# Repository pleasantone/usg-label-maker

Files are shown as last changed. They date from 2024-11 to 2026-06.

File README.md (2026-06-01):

# usg-label-maker

## Introduction

This is a magnetic label generator that I use to create my labels
for my Harbor Freight US General series tool boxes/tool carts.  You
can easily make a batch of custom labels for tool carts and tool
boxes.

The label generator is written to work either with the Makerworld
Parametric Model Maker (aka the Customize button) or on a local
copy of [OpenSCAD](https://openscad.org/downloads.html#snapshots).

The included .3MF project includes a ton of labels you can use on
their own, but it was my intention that you would use this to make
your own custom labels.

We print these labels with the magnet side down to the bed. The
little amount of bridging needed means that supports should not be
needed.

### Remix Differences

Originally written by Josh who produced a single label. This is
complete rewrite of that code to support batch generation, the
customizer, guardrails, and multi-part and multi-plate printing.
His code was the inspiration for this code.

## Usage

### Option 1: MakerWorld Customizer Button

#### Pros:
- Nothing to install, just customize, download, and print.
- Supports generating up to 5 plates at once.

#### Cons:

You must use one of the fonts supported by the customizer, which
does not include any that match the US General font. Montserrat is
kind of close, but not fantastic.

1. Use the customizer to set the labels you wish to print.
   Labels are delimited with the “|” character.
1. Generate, download
1. Slice and print.

### Option 2: Local OpenSCAD

#### Pros:
- Not limited to Makerworld's font library.

#### Cons:
- More complicated
- Requires OpenSCAD and font installation
- Only supports one plate at a time.
- Base and text are exported as two different parts of the object--just select which color filament to use for each part.

1. Install OpenSCAD development snapshot. The last official release is from 2021 but it is actively maintained and we use features that do not exist in the official release. Hint: if using a recent MacOS, you may need to remove the quarantine flag from the downloaded file before it will run.
1. Download/install desired fonts (see Getting the Fonts below).
1. Go to **OpenSCAD > Preferences > Features** and enable lazy-union and text-metrics.
1. Go to **OpenSCAD > Preferences > Advanced** and set the 3D Rendering backend to **Manifold**.
1. Download the `.SCAD` file, edit it and set `MakerWorld_Customizer_Environment` to `false` (it defaults to `true` for the customizer).
1. Use the OpenSCAD customizer window or edit the source code to set the labels you wish to print. *Labels are delimited with the “|” character.*
1. If using a different font, set the name of the font in OpenSCAD.
1.  Do a preview rendering (F5), if it looks good, do a slower full rendering (F6), then Export the output as a .3MF file.
1. Load the .3MF file into your slicer, answer Yes when the slicer prompts “Multi-part object detected.”
1. Go to Objects menu, “OpenSCAD Model 1” represents all the bases, “OpenSCAD Model 2” is all of the text parts. Set desired colors or filament for each part.

## Getting the fonts

You can use any TTF font you want. You can either copy the font
file into the same directory as the .scad file, or install it in
your system fonts.

The default local font is **sd prostreet**, which works well and is
freely available.

As a backup, Fontspring's [Avionic Wide Oblique
Black](https://www.fontspring.com/fonts/grype-type/avionic) is the
closest match to the actual USG font. The sample pictures were
taken with their Demo license copy so you can easily test --
obviously you should either change fonts or buy a personal license
should you use this for a finished project or commercially.

## Interesting Parameters/Variables

See the .scad file for parameters you can change, but briefly:

- *MakerWorld_Customizer_Environment*: Running on MakerWorld (true) or locally (false)?
- *plate_labels_1*..*plate_labels_5*: label names, each delimited with "|" like "SOCKETS|RATCHETS|ALLEN WRENCHES" (only plate_labels_1 is rendered locally)
- *font*: font to use; defaults follow the environment
- *font_size*: 8mm default
- *depth*: 5mm default total badge thickness -- includes raised letters
- *base_outline*:
     0: default, a rectangle with rounded corners
     1: Flows base shape to follow letter outlines.
        May produce more aesthetic results but can also look
        strange letters with descenders (angled base) and trailing Ls
        (opposite angle). Slower to render but could be very cool.

### Layout, exclusion zones, and the preview border

Labels are 2D bin-packed to fill the bed on both axes, not just stacked in a
single column. If more labels are requested than fit, rendering stops with an
assertion that names the labels it couldn't place — reduce the label count or
`font_size`, shrink the exclusion zones, or split the set across plates.

- *exclude_zone_1* / *exclude_zone_2*: optional rectangular keep-out areas the
  packer routes around, each anchored to a bed corner via its `_corner` and
  `_size` ([width, height] mm) parameters. Defaults reserve the Bambu X1C
  front-left cutter/wipe area and a prime-tower space at the top-right.
  Enabling zones reduces usable area, so a set that fit without them may
  overflow.
- *border_thickness*: width of a red reference frame drawn just outside the bed
  edges. Together with the translucent red exclusion-zone overlays it appears
  only in on-screen preview (F5) and is never part of any STL/3MF export.

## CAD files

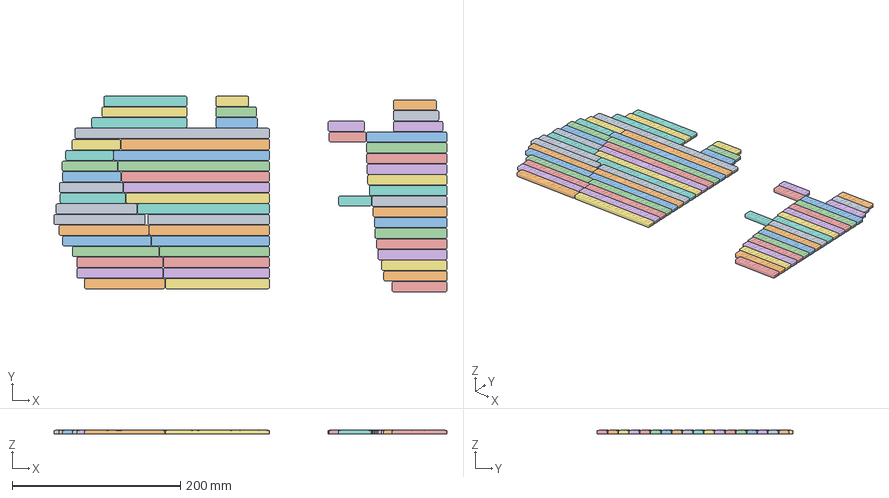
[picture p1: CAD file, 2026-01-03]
samples/New Labels (2 plates).3mf
466.9 x 232.6 x 5.00 mm
part_electrical-diagnostics.stl
part_torque-wrenches.stl
part_specialty-sockets.stl
part_automotive-tools.stl
part_impact-wrenches.stl
part_metric-wrenches.stl
part_electrical-tools.stl
part_metric-sockets.stl
part_screwdrivers.stl
part_sae-wrenches.stl
part_breaker-bars.stl
part_power-tools.stl
part_brake-tools.stl
part_sae-sockets.stl
part_motorcycle.stl
part_extensions.stl
part_measuring.stl
part_electrical.stl
part_hardware.stl
part_adhesives.stl
part_soldering.stl
part_vise-grips.stl
part_wrenches.stl
part_drill-bits.stl
part_air-tools.stl
part_pry-bars.stl
part_ratchets.stl
part_sealants.stl
part_crimpers.stl
part_hammers.stl
part_no-touch.stl
part_hex-keys.stl
part_magnets.stl
part_brushes.stl
part_marking.stl
part_sockets.stl
part_riveting.stl
part_bit-sets.stl
part_chisels.stl
part_snacks.stl
part_shears.stl
part_zip-ties.stl
part_metric.stl
part_lights.stl
part_pliers.stl
part_allen.stl
part_picks.stl
part_paint.stl
part_junk.stl
part_torx.stl
part_misc.stl
part_tape.stl
part_bits.stl
part_oils.stl
part_sae.stl
part_ppe.stl

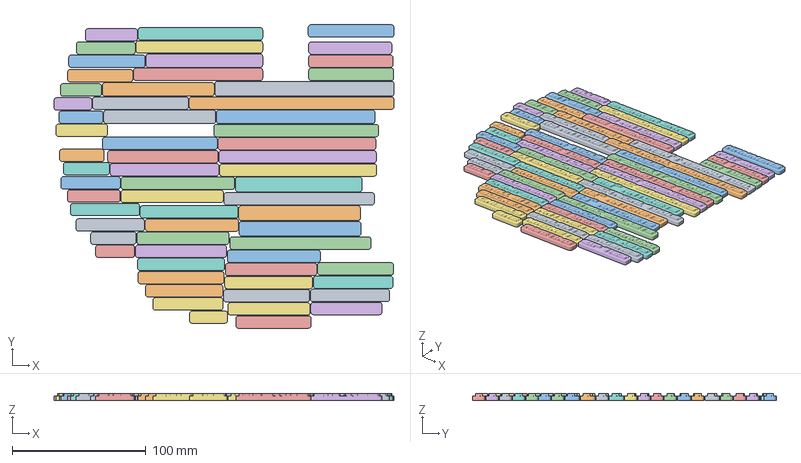
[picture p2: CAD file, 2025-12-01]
samples/sample label objects.3mf
253.9 x 226.7 x 5.50 mm
part_i-wasnt-asking-tool.stl
part_electrical-diagnostics.stl
part_torque-wrenches.stl
part_specialty-sockets.stl
part_automotive-tools.stl
part_impact-wrenches.stl
part_metric-wrenches.stl
part_38--ratchets.stl
part_electrical-tools.stl
part_12--ratchets.stl
part_14--ratchets.stl
part_metric-sockets.stl
part_sae-wrenches.stl
part_38-ratchets.stl
part_screwdrivers.stl
part_breaker-bars.stl
part_12-ratchets.stl
part_14-ratchets.stl
part_power-tools.stl
part_sae-sockets.stl
part_brake-tools.stl
part_motorcycle.stl
part_extensions.stl
part_measuring.stl
part_electrical.stl
part_hardware.stl
part_wrenches.stl
part_adhesives.stl
part_vise-grips.stl
part_soldering.stl
part_ratchets.stl
part_crimpers.stl
part_sealants.stl
part_drill-bits.stl
part_hammers.stl
part_air-tools.stl
part_no-touch.stl
part_pry-bars.stl
part_magnets.stl
part_hex-keys.stl
part_brushes.stl
part_sockets.stl
part_bit-sets.stl
part_marking.stl
part_riveting.stl
part_zip-ties.stl
part_chisels.stl
part_shears.stl
part_snacks.stl
part_metric.stl
part_pliers.stl
part_lights.stl
part_paint.stl
part_allen.stl
part_picks.stl
part_tape.stl
part_misc.stl
part_junk.stl
part_torx.stl
part_bits.stl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

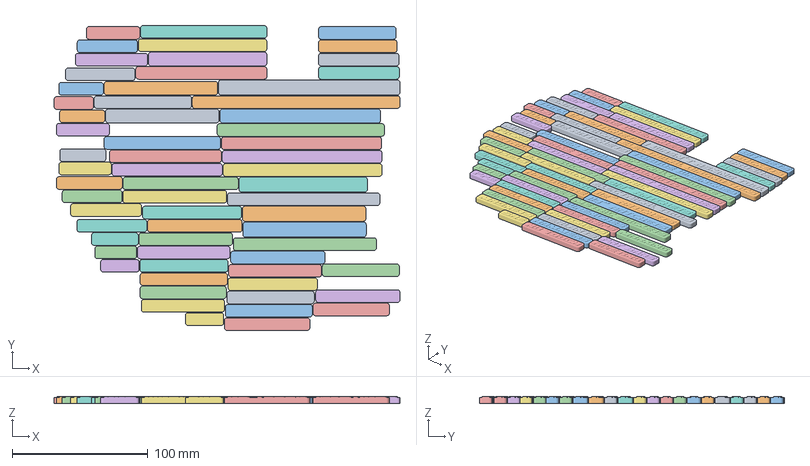
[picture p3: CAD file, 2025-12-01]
samples/MagneticLabelMaker.3mf
254.7 x 224.5 x 5.00 mm
part_i-wasnt-asking-tool.stl
part_electrical-diagnostics.stl
part_torque-wrenches.stl
part_specialty-sockets.stl
part_automotive-tools.stl
part_impact-wrenches.stl
part_metric-wrenches.stl
part_38--ratchets.stl
part_electrical-tools.stl
part_12--ratchets.stl
part_14--ratchets.stl
part_metric-sockets.stl
part_sae-wrenches.stl
part_38-ratchets.stl
part_screwdrivers.stl
part_breaker-bars.stl
part_12-ratchets.stl
part_14-ratchets.stl
part_power-tools.stl
part_sae-sockets.stl
part_brake-tools.stl
part_motorcycle.stl
part_extensions.stl
part_measuring.stl
part_electrical.stl
part_hardware.stl
part_wrenches.stl
part_adhesives.stl
part_vise-grips.stl
part_soldering.stl
part_ratchets.stl
part_crimpers.stl
part_sealants.stl
part_drill-bits.stl
part_hammers.stl
part_air-tools.stl
part_no-touch.stl
part_pry-bars.stl
part_magnets.stl
part_hex-keys.stl
part_brushes.stl
part_sockets.stl
part_bit-sets.stl
part_marking.stl
part_riveting.stl
part_zip-ties.stl
part_chisels.stl
part_shears.stl
part_snacks.stl
part_metric.stl
part_pliers.stl
part_lights.stl
part_paint.stl
part_allen.stl
part_picks.stl
part_tape.stl
part_misc.stl
part_junk.stl
part_torx.stl
part_bits.stl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

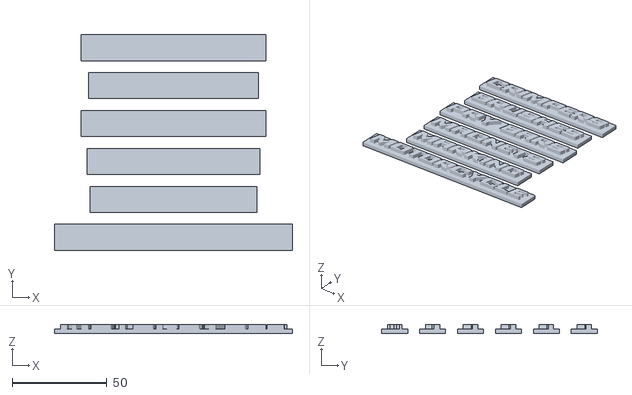
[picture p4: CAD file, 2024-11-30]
samples/labels3.stl
125.7 x 113.8 x 5.00

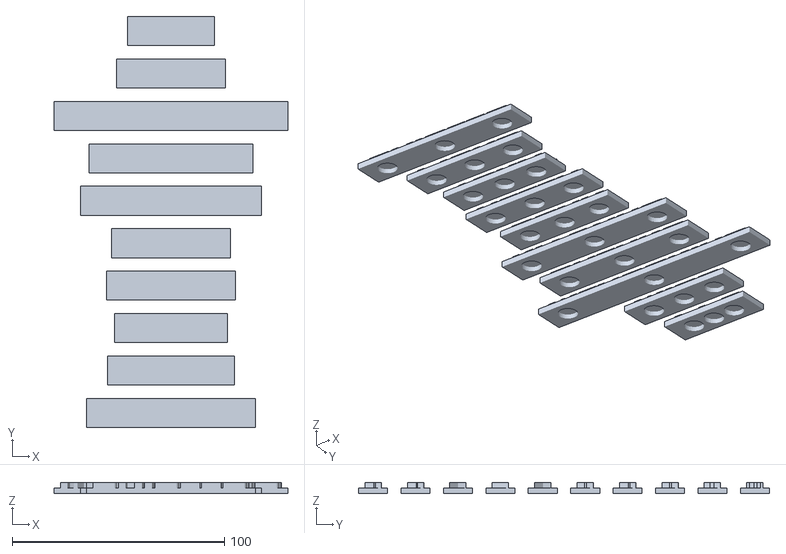
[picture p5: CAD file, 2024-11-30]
samples/labels2.stl
110.2 x 193.8 x 5.00

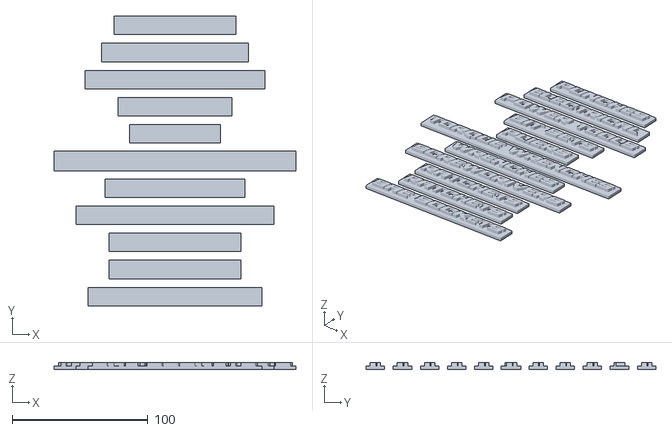
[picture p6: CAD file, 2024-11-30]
samples/labels1.stl
178.4 x 213.8 x 5.00

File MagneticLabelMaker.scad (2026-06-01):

/*
  Magnetic Label Maker by Pleasant One remixed from Josh
  See documentation for License.
  
  We have two similar but different working environments, OpenSCAD locally or
  online with a customizer like Makerworld's Parametric Model Maker
  
  With MakerWorld's product, we can support up to five plates of
  labels to be generated at once. MakerWorld's extensions allow for
  encoding color information in the .3mf.

  However, MakerWorld cannot add user fonts, so we can't get the
  closest US General matching font.  I have found that MakerWorld's
  Montserrat Extra Bold Italic is moderately close.

  With OpenSCAD locally, we only support producing one (the first)
  plate at a time.  You can generate either .STL files or .3MFs but
  no color information will be encoded.  The output file will contain
  two object parts, the base of and the text.  Load both parts
  together using your slicer, and then use your slicer to assign
  color information.
*/

// usg-label-maker release 1.0.0  (x-release-please-version -- auto-updated; do not edit by hand)

// Are we running on MakerWorld or a local instance of OpenSCAD?
MakerWorld_Customizer_Environment = true;

// The labels to print, delimited by "|"
plate_labels_1 = "METRIC SOCKETS|SAE SOCKETS|SPECIALTY SOCKETS|RATCHETS|SCREWDRIVERS|WRENCHES|TORQUE WRENCHES|PLIERS|BIT SETS|POWER TOOLS|ELECTRICAL|CHISELS|PICKS|TORX|ALLEN|JUNK|RIVETING|SHEARS|MEASURING|MISC|PPE|MOTORCYCLE|MARKING|MAGNETS|PRY BARS|BRUSHES|CRIMPERS|SOLDERING|HAMMERS|LIGHTS|ZIP TIES|TAPE|DRILL BITS|ADHESIVES|SEALANTS|AUTOMOTIVE TOOLS|OILS|PAINT|BRAKE TOOLS|HAMMERS|SAE WRENCHES|METRIC WRENCHES|VISE GRIPS|AIR TOOLS|POWER TOOLS|SNACKS|ELECTRICAL TOOLS|ELECTRICAL DIAGNOSTICS|SOCKETS|ELECTRICAL|NO TOUCH|BITS|IMPACT WRENCHES";

// Multiple plate support only works on MakerWorld
plate_labels_2 = "1/4\" RATCHETS|3/8\" RATCHETS|1/2\" RATCHETS";
plate_labels_3 = "I WASN'T ASKING TOOL";
plate_labels_4 = "DON'T TOUCH MY TOOLS";
plate_labels_5 = "PLATE 5 ITEMS";

/* [Fonts] */
/* A note on fonts:

   If you are intending to match the US General font, it is non-standard
   and is not installed on either OpenSCAD or with MakerWorld. You will need
   to download a closely matching font.
   
   The best font available on MakerWorld is Montserrat Extra Bold Italic.

   For local operation, where you can use any font you find on the web,
   the default is sd prostreet. Avionic Wide Oblique Black is the closest
   match to the actual USG font but is only available as a Fontspring demo
   download -- use it as a backup if you want the closer look. Any of these
   work well:

   https://www.ffonts.net/sdprostreet-Regular.font     (default)
   https://demofont.com/avionic-sans-serif-font/       (backup: closest USG match, demo license)
   https://www.ffonts.net/Concielian-Bold-Semi-Italic.font  (backup)

   Download one or more of them and unpack.
   Install the downloaded font(s) to your system. (On a Mac, double-click the .ttf and install.)

   You might need to restart OpenSCAD in order for it to recognize
   newly installed or "used' fonts.

   The sample pictures were taken with Avionic Wide Oblique Black's demo.
*/

// Default font follows the environment: Montserrat on MakerWorld (only fonts in
// their library are available), sd prostreet locally. Override in the customizer
// or via OpenSCAD -D for batch runs.
// Backup local options:
//   "FONTSPRING DEMO \\- Avionic Wide Oblique Black" -- closest USG match (demo license)
//   "Concielian:style=Bold Semi Italic"

// font used with makerworld customizer
makerworld_font = "Montserrat:style=ExtraBold Italic"; //font

// font used when running local OpenSCAD
local_font = "sd prostreet";

font = MakerWorld_Customizer_Environment ? makerworld_font : local_font;

// Font size in points
font_size = 8; // [5:32]

/* [Colors] */
// Base color
base_color = "#000000"; // color

// Text color
text_color = "#FFFFFF"; // color

/* [Details] */
/*
   If base_outline is true, the base will flow with letter shapes. It is slower
   to render and could be unaesthetic when using letters with descenders
   (Q) or trailing characters with reverse angles (L). It's very pretty
   when it works out correctly but, to be safe, we leave this off by default.
*/

// Should the base follow an outline of the letters? (see notes!)
base_outline = 0; // [0: Standard base, 1: Follow letter shapes]

// Rounded corner radius in mm
base_radius = 2;

// Total depth in mm of badge and base in mm
depth = 5;

// Diameter of the magnet hole in mm
magnet_diameter = 8;

// Depth of the magnet hole in mm
magnet_depth = 3;

// Fully encapsulated magnets or open at the base. If encapsulate, pause the print at the top of the hole to insert magnets
encapsulate_magnets = false;

// place magnet holes in mm from inside edge
magnet_edge_inboard = 10;

// minimum separation in mm between outer holes before dropping to one hole
magnet_minimum_separation = 2;

// if piece is >mm wide, add a center hole
magnet_center_hole_width = 60;

/* [Printer dimensions] */
// printer bed size (BambuLab A1/P1/X1 are approximately 255mmx255mm)
bed_size=[255, 255];

// Wall width in mm of the preview-only plate-edge border (never exported)
border_thickness = 3;

// Skip rectangular keep-out areas when arranging labels (each anchored to a bed
// corner). Sizes are [width, height] in mm.

// Zone 1 default: Bambu X1C front-left cutter / nozzle-wipe area (tune to taste)
exclude_zone_1 = true;
exclude_zone_1_corner = "left-bottom"; // [left-bottom, right-bottom, left-top, right-top]
exclude_zone_1_size = [18, 28];

// Zone 2 default: space reserved for a prime / purge tower
exclude_zone_2 = true;
exclude_zone_2_corner = "right-top"; // [left-bottom, right-bottom, left-top, right-top]
exclude_zone_2_size = [55, 55];

/* [Advanced] */
// Extra padding for magnet cut on Z axis
magnet_depth_clearance = 0.1;
// Extra padding for magnet at top of cut
magnet_topcyl_clearance = 0.1;
// Extra padding for magnet at bottom of cut
magnet_bottomcyl_clearance = 0.2;

// lower Z bounds of magnet cut
magnet_depth_offset = encapsulate_magnets ? magnet_depth_clearance * 2 : 0;
magnet_hole_bore = magnet_depth + magnet_depth_clearance;
magnet_hole_top = magnet_hole_bore + magnet_depth_offset;
// the .1 is slop so we can get enough material around the magnet
magnet_wrap_diameter = magnet_diameter + magnet_bottomcyl_clearance; // + 0.042;

// Safety gap in mm between neighbouring label footprints (applied on both axes)
label_gap = 1;

/* [ Hidden ] */

base_depth = magnet_hole_top + (magnet_depth_clearance*2);

// Active exclusion zones as rectangles [x_min, y_min, x_max, y_max] in the same
// bed-centered coordinate system the labels are placed in.
exclusion_zones = concat(
    exclude_zone_1 ? [corner_rect(exclude_zone_1_corner, exclude_zone_1_size, bed_size)] : [],
    exclude_zone_2 ? [corner_rect(exclude_zone_2_corner, exclude_zone_2_size, bed_size)] : []
);

$fn = 32; // Model detail, higher is more detail and more processing

/* -------------------------------------------------------------------------- */

/* Maker World Multi-plate
   The following modules will only be executed when using the
   Parametric Model Maker.
   
   We define specific modules for each plate.
   
   The name of module should be in syntax: mw_plate_1(), mw_plate_2(), etc.
*/

module mw_plate_1(labels=plate_labels_1) mw_make_labels(labels);
module mw_plate_2(labels=plate_labels_2) mw_make_labels(labels);
module mw_plate_3(labels=plate_labels_3) mw_make_labels(labels);
module mw_plate_4(labels=plate_labels_4) mw_make_labels(labels);
module mw_plate_5(labels=plate_labels_5) mw_make_labels(labels);

module mw_make_labels(labels) {
    color(base_color) iterate_labels(labels) make_base();
    color(text_color) iterate_labels(labels) make_text();
}

/* Local OpenSCAD:

   If we are using the development snapshot of OpenSCAD with the lazy_union
   enabled, each "top level" creation will be its own object part.
   This is an easy way to handle color changes.
   
   Import the .3mf file into your slicer, click "Yes" when it asks to
   bring in multiple objects as parts of one single object, and it will
   position each part correctly.
   
   Then go into the object menu and set filaments as you want them colored.
*/

if (!MakerWorld_Customizer_Environment) {
    color(base_color)
        iterate_labels(plate_labels_1)
            make_base(); // all the bases will export as a single object

    color(text_color)
         iterate_labels(plate_labels_1)
            make_text(); // all the text will export as a single object
}

// Reference frame around the bed edges plus the exclusion-zone overlays.
// $preview is true only for on-screen preview (F5); it is false during full
// render and every export (F6, CLI -o, MakerWorld), so these never become part
// of any STL/3MF.
if ($preview) {
    plate_border();
    plate_exclusions();
}


/* ------------------------ */
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

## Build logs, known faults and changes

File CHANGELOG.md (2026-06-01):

# Changelog

All notable changes to this project are documented in this file. From v1.0.0
onward it is maintained automatically by
[release-please](https://github.com/googleapis/release-please) from
[Conventional Commits](https://www.conventionalcommits.org/); newer releases are
prepended above the 1.0.0 entry.

## [1.0.0](https://github.com/pleasantone/usg-label-maker/releases/tag/v1.0.0) (2026-05-31)

Complete rewrite of the original single-label remix into a batch/customizer
generator. Summary of the current behavior:

### Added

- **2D bin-packing layout.** `iterate_labels` measures each label once, grows its
  text box by `2 * base_radius` per axis (floored at `magnet_wrap_diameter` so
  the base never shrinks below its magnet pocket), then lays a centered grid of
  uniform-height row-bands and packs labels widest-first (first-fit decreasing)
  into the free X-intervals of each band. Fills the bed on both axes; the
  placement assertion names any labels that couldn't be placed.
- **Configurable exclusion zones.** Two corner-anchored keep-out rectangles
  (`exclude_zone_1/2`, each with `_corner` and `_size`) that the packer routes
  around — defaults reserve the Bambu X1C front-left cutter/wipe area
  (18×28mm) and a prime-tower space (55×55mm). Zones reduce usable area, so a
  set that fit without them may overflow.
- **Preview-only reference geometry.** `plate_border()` frames the bed just
  outside its edges (`border_thickness`, default 3mm) and `plate_exclusions()`
  overlays the keep-out zones in translucent red. Both are gated by `$preview`,
  so they appear in on-screen preview (F5) but never enter any STL/3MF export.
- **Hardened `batchmake.sh`.** One STL per badge from a newline-delimited list
  (blank/`#` lines skipped), `set -euo pipefail`, pre-flight checks (binary,
  source, input, output dir), `[N/total]` progress, `-h`/`--help`, `OPENSCAD`
  env override, a `loadout` preset (smaller magnets → `./loadout/`), label
  escaping for `"`/`\`, and filename sanitization with an `unnamed` fallback.
- `CLAUDE.md` with architecture notes and build/batch commands.

### Changed

- **Default font follows the environment** — `"Montserrat:style=ExtraBold
  Italic"` on MakerWorld, `"sd prostreet"` locally (mirrored by `batchmake.sh`);
  Avionic Wide Oblique Black documented as the closest-USG-match backup.
  Customizer and `-D font=...` overrides still take precedence.
- **`textmetrics` computed once per label** and propagated via `$tmetrics`, so
  `make_base`/`make_text` never re-measure.
- **Magnet placement extracted to `place_magnet_holes()`** — the
  two-vs-one-vs-three-hole decision, with edge-to-edge gap math that correctly
  treats `magnet_diameter / 2` as the per-side radius.
- **Single `label_gap` safety margin** (default 1mm, both axes) replaces the
  old `label_y_extra_spacing`.

### Fixed

- **Bed-fit math.** The X assertion now accounts for `minkowski` adding
  `base_radius` on **both** sides (`base_width + 2 * base_radius`), and base
  width/height are both floored at `magnet_wrap_diameter` so a short label
  (e.g. `"A"`) can't let its magnet pocket break through the wall.
- **`make_text` asserts `depth > base_depth`** instead of silently emitting no
  text when `depth` falls below the magnet-driven minimum.
- **Delimiter-only strings** like `"|"` no longer render ghost labels —
  `iterate_labels` filters empty entries and skips an otherwise-empty render.
- **`batchmake.sh` robustness:** parses correctly (the `avionic` case had a
  missing `;;`), no longer trips `set -u` on `OUTDIR`, keeps the last badge when
  the file lacks a trailing newline, errors on unknown options / extra
  arguments / unknown presets, resolves the `.scad` path relative to itself
  (works from any CWD), and applies the `loadout` preset's real variable names.
- **README** parameter names and instructions match the current code (`font_size`,
  `depth`, `base_outline`, `plate_labels_1`..`5`,
  `MakerWorld_Customizer_Environment`, 5 plates, both-axes packing).

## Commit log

2024-11-30 Initial import into git
    [MagneticLabelMaker.3mf, MagneticLabelMaker.scad]
2024-11-30 Add STL files for my personal labels
    [labels1.stl, labels2.stl, labels3.stl]
2024-11-30 Improve baseplate generation
    [MagneticLabelMaker.scad]
2024-12-01 Fix bogus warning
    [MagneticLabelMaker.scad]
2024-12-09 Parameterize everything for Bambu Customizer/OpenSCAD
    [MagneticLabelMaker.3mf, MagneticLabelMaker.scad]
2024-12-13 chore: Don't track fonts in git
2025-01-17 feat: Make labels '|' delimited strings so customizer can access them
    [MagneticLabelMaker.scad]
2025-01-17 Add selections for fonts
    [MagneticLabelMaker.scad]
2025-01-24 feat: separate each label into its own object
    [MagneticLabelMaker.scad]
2025-01-24 Separate each base and text
    [MagneticLabelMaker.scad]
2025-01-24 feat: Split all of the bases and texts into two separate objects
    [MagneticLabelMaker.3mf, MagneticLabelMaker.scad]
2025-01-25 fix: eliminate duplicate code
    [MagneticLabelMaker.scad]
2025-01-25 feat: Plates with all the examples
    [MagneticLabelMaker.3mf]
2025-03-16 fix: reformatting, use //font, add comment about restart
    [MagneticLabelMaker.scad]
2025-08-04 v7: Better MakerWorld support and documentation
    [MagneticLabelMaker.scad]
2025-09-17 Allow magnets to be embedded, fix depth calculations
    [MagneticLabelMaker.3mf, MagneticLabelMaker.scad]
2025-09-17 Simplify avionic font specification
    [MagneticLabelMaker.scad]
2025-09-17 Convert assert to warning, allow font size to 75, start at xyz=0
    [MagneticLabelMaker.scad]
2025-09-17 Make magnet depth 3 to match BOM
    [MagneticLabelMaker.scad]
2025-09-17 Revert XY alignment, make sure text doesn't overlap base
    [MagneticLabelMaker.scad]
2025-09-22 Allow setting of label intergap spacing
    [MagneticLabelMaker.scad]
2025-09-23 fix: calculate height exactly, autodetect makerworld, cleanup
    [MagneticLabelMaker.scad]
2025-09-23 Convert warnings to asserts so they will be visible on PMM
    [MagneticLabelMaker.scad]
2025-11-12 Autodetect is too fragile, go back to asking.
    [MagneticLabelMaker.scad]
2025-12-01 Create batches of compressed labels
    [sample label objects.3mf]
2025-12-01 Redo all the depth and tolerance math and clean up
    [MagneticLabelMaker.3mf, MagneticLabelMaker.scad]
2025-12-22 Make sure there is enough material around magnet hole. Make the third magnet configurable by magnet length.
    [MagneticLabelMaker.scad]
2026-01-03 New Label Samples
    [New Labels (2 plates).3mf]
2026-05-28 Fix layout and magnet placement bugs, harden batchmake, add CHANGELOG and CLAUDE.md
    Rendering fixes in MagneticLabelMaker.scad:
    - X-axis bed assertion now accounts for both minkowski sides (2 * base_radius)
    - Center labels inside their Y slot so the first label no longer overhangs the back of the bed
    - Tighten the top-edge Y assertion to recover ~1.5 slots of usable plate
    - Correct magnet edge-to-edge gap calculation (was over by one full diameter)
    - Assert depth > base_depth in make_text instead of silently producing no text
    - Filter empty entries after splitting so "|" no longer renders ghost labels
    - Cache textmetrics once per label, propagate via $tmetrics special variable
    - Extract magn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
    [MagneticLabelMaker.scad]
2026-05-29 Move outputs to samples
    [MagneticLabelMaker.3mf, New Labels (2 plates).3mf, labels1.stl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]
2026-05-31 Grid-pack labels and add preview-only plate border
    Replace the single centered-column layout with first-fit-decreasing
    shelf bin-packing so labels fill the bed on both axes: iterate_labels
    now measures each label's full footprint, sorts widest-first, and packs
    rows centered on the bed origin. Adds the sorted_desc/first_fit/pack
    helpers and a single label_gap safety parameter (both axes), replacing
    label_y_extra_spacing.
    Add plate_border(), a square frame at the bed edges gated by $preview so
    it shows on-screen but is excluded from every render/export.
    Update CLAUDE.md and CHANGELOG to document both.
    [MagneticLabelMaker.scad]
2026-05-31 Ignore OpenSCAD customizer parameter file
    MagneticLabelMaker.json is a local GUI artifact (customizer parameter
    sets), not source.
2026-05-31 Route label packing around configurable exclusion zones
    Add two corner-anchored keep-out rectangles (exclude_zone_1/2, with
    _corner and _size params). Defaults reserve the X1C front-left cutter
    area (18x18, left-bottom) and a 100x100 prime-tower space (right-top).
    Rework iterate_labels: lay a centered grid of row-bands, carve each band
    into the free X-intervals left between the zones (inflated by label_gap),
    and first-fit-decreasing pack labels into those shelves. The placement
    assertion now lists any labels that didn't fit. New helpers: corner_rect,
    inflate, band_blockers, free_intervals/sweep, sort_by_lo, fit_shelf,
    pack_shelves (replacing the row-based first_fit/pack).
    plate_exclusions(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
    [MagneticLabelMaker.scad]
2026-06-01 Render border outside the bed; font/param refactor; doc sync
    - plate_border() now draws just outside the bed edges (inner edge at
    bed_size, extending border_thickness beyond) so it frames the bed
    without consuming printable area.
    - Split font selection into makerworld_font / local_font variables under
    a [Fonts] customizer group; font picks between them on the environment.
    - Reorganize the default plate_labels_* lists and tune the default
    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
    [MagneticLabelMaker.scad]
2026-06-01 Fix batchmake parse/unbound bugs, clamp narrow-label bases, sync docs
    - batchmake.sh: add the missing ;; on the avionic case (the script failed
    to parse at all) and initialize OUTDIR so default/avionic runs don't hit
    an unbound-variable error under set -u.
    - make_base/iterate_labels: clamp base width to magnet_wrap_diameter (height
    was already clamped) so a narrow label's magnet pocket can't break through
    the side wall; the packer applies the same clamp so the reserved slot
    matches the rendered base.
    - CHANGELOG: correct the bin-packing entry to the current shelf helpers
    (fit_shelf/pack_shelves) and drop the stale "joins plate_labels_1..5"
    claim (local path renders only plate_l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
    [MagneticLabelMaker.scad]
2026-06-01 Collapse Unreleased changelog to final-state summary
    The Unreleased section had grown into a fix-by-fix log, much of it describing
    intermediate code states that never shipped (e.g. per-slot Y centering and a
    top-edge assertion both superseded by the grid packer). Consolidated it into a
    concise Added/Changed/Fixed summary of the current behavior.
2026-06-01 Clean up defaults so it works on Makerworld
    [MagneticLabelMaker.scad]
2026-06-01 chore(release): bootstrap release-please at 1.0.0
    Automate versioning/changelog with release-please (release-type: simple).
    Adds the GitHub Action, config + seeded manifest, version.txt, an
    x-release-please-version stamp comment in MagneticLabelMaker.scad, and a
    Releases section in CLAUDE.md. Re-labels the hand-written changelog section
    as the 1.0.0 bootstrap release.
    [MagneticLabelMaker.scad]
2026-10-13 fix: stop the base silently growing 1 mm and burying the text
    The minkowski with a cylinder(h=1) added 1 mm to the base, so the base
    top sat at base_depth + 1 while make_text started at base_depth: the
    bottom 1 mm of every letter was hidden inside the base, and the
    depth > base_depth assert didn't actually guarantee visible text.
    Round the base in 2D (offset + hull) instead, and make the extra
    material explicit as magnet_cap_thickness (default 1 mm). Printed
    geometry is unchanged at default settings.
    Claude-Session: https://claude.ai/code/session_01H72FJh9tkoxMBscb9xkCg2
2026-10-13 feat: add inlay and deboss text styles, optional face-down printing and elephant's foot compensation
    text_style = raised | inlay | deboss. inlay is flush two-color text and
    deboss is recessed text with no separate text part; both make the base
    solid for the full depth and cut the text text_depth into the face.
    print_face_down = true (inlay/deboss only; raised is an error) builds
    the label with the face on the bed: the text is mirrored and the magnet
    pockets open on top, with the pocket cone mirrored so its wide end stays
    at the opening. Asserts guard the first-layer and magnet-cap clearances.
    elephant_foot (default 0, since most slicers already compensate) with
    first_layer_height insets th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
